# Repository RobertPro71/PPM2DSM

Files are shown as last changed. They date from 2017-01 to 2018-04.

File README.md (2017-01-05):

# PPM2DSM
Control with any transmitter a model with DSM receiver. All information about build, programming and use are here:
www.demoboard.de

## Folder Description

###Layout

The first modul. To build as a single modul that is temporarily connected to the transmitter.

### Layout_fix

A mod of the original converter. To use as fix connection to transmitter.

### Source

Sourcecode written in Arduino with all build tools.

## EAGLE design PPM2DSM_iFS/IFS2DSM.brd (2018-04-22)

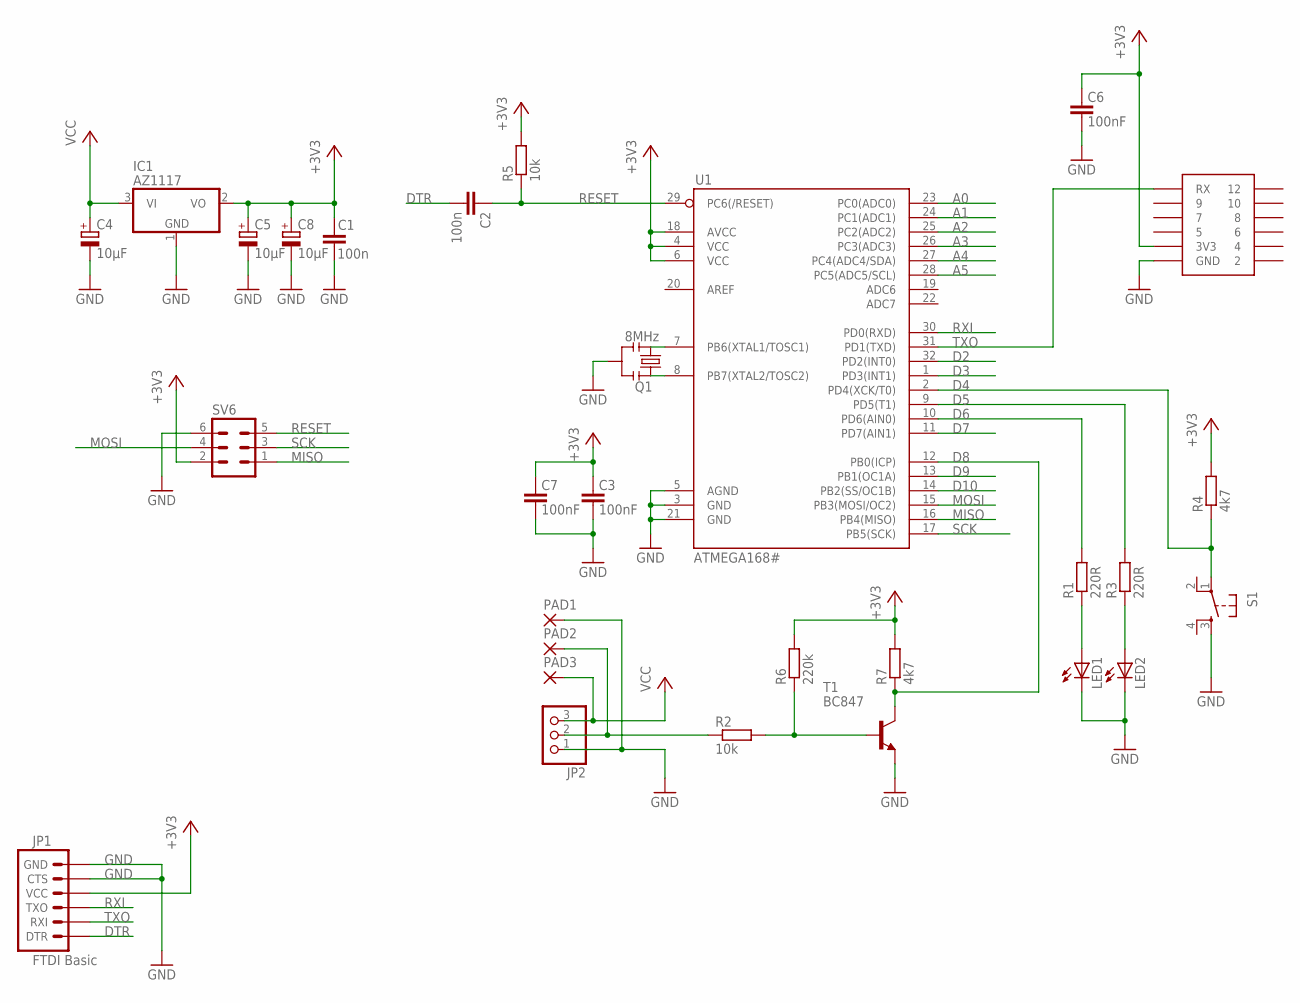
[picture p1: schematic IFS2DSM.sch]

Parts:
C1, C2: 100n; C0805
C3, C6, C7: 100nF; C0805
C4, C5, C8: 10µF; CT6032
IC1: AZ1117; SOT223
IC3: X1TX0
JP1: FTDI Basic; 1X06
JP2: PINHD-1X3_2.00; 1X03M
LED1, LED2: LEDSML0805; SML0805
PAD1, PAD2, PAD3: SMD2; SMD1,27-2,54
Q1: 8MHz; RESONATOR-SMD
R1, R3: 220R; R0805
R2, R5: 10k; R0805
R4, R7: 4k7; R0805
R6: 220k; R0805
S1: 10-XXTASTERSMD; SMD
SV6: MA03-2
T1: BC847; SOT23
U1: ATMEGA168#; TQFP32-08

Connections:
2: IC3.2
4: IC3.4
+3V3: C1.2, C3.2, C5.+, C6.2, C7.2, C8.+, IC1.2 (VO), IC3.3 (3V3), JP1.4 (VCC), R4.2, R5.2, R6.2, R7.2, SV6.2, U1.4 (VCC), U1.6 (VCC), U1.18 (AVCC)
A0: U1.23 (PC0(ADC0))
A1: U1.24 (PC1(ADC1))
A2: U1.25 (PC2(ADC2))
A3: U1.26 (PC3(ADC3))
A4: U1.27 (PC4(ADC4/SDA))
A5: U1.28 (PC5(ADC5/SCL))
D2: U1.32 (PD2(INT0))
D3: U1.1 (PD3(INT1))
D4: R4.1, S1.1, U1.2 (PD4(XCK/T0))
D5: R3.2, U1.9 (PD5(T1))
D6: R1.2, U1.10 (PD6(AIN0))
D7: U1.11 (PD7(AIN1))
D8: R7.1, T1.3 (C), U1.12 (PB0(ICP))
D9: U1.13 (PB1(OC1A))
D10: U1.14 (PB2(SS/OC1B))
DTR: C2.2, JP1.1 (DTR)
GND: C1.1, C3.1, C4.-, C5.-, C6.1, C7.1, C8.-, IC1.1 (GND), IC3.1 (GND), JP1.5 (CTS), JP1.6 (GND), JP2.1, LED1.C, LED2.C, PAD1.1, Q1.2, S1.3 (S), SV6.6, T1.2 (E), U1.3 (GND), U1.5 (AGND), U1.21 (GND)
MISO: SV6.1, U1.16 (PB4(MISO))
MOSI: SV6.4, U1.15 (PB3(MOSI/OC2))
unnamed: Q1.1, U1.8 (PB7(XTAL2/TOSC2))
unnamed: Q1.3, U1.7 (PB6(XTAL1/TOSC1))
unnamed: LED2.A, R3.1
unnamed: R2.2, R6.1, T1.1 (B)
unnamed: JP2.2, PAD2.1, R2.1
unnamed: LED1.A, R1.1
RESET: C2.1, R5.1, SV6.5, U1.29 (PC6(/RESET))
RXI: JP1.3 (TXO), U1.30 (PD0(RXD))
SCK: SV6.3, U1.17 (PB5(SCK))
TXO: IC3.11 (RX), JP1.2 (RXI), U1.31 (PD1(TXD))
VCC: C4.+, IC1.3 (VI), JP2.3, PAD3.1

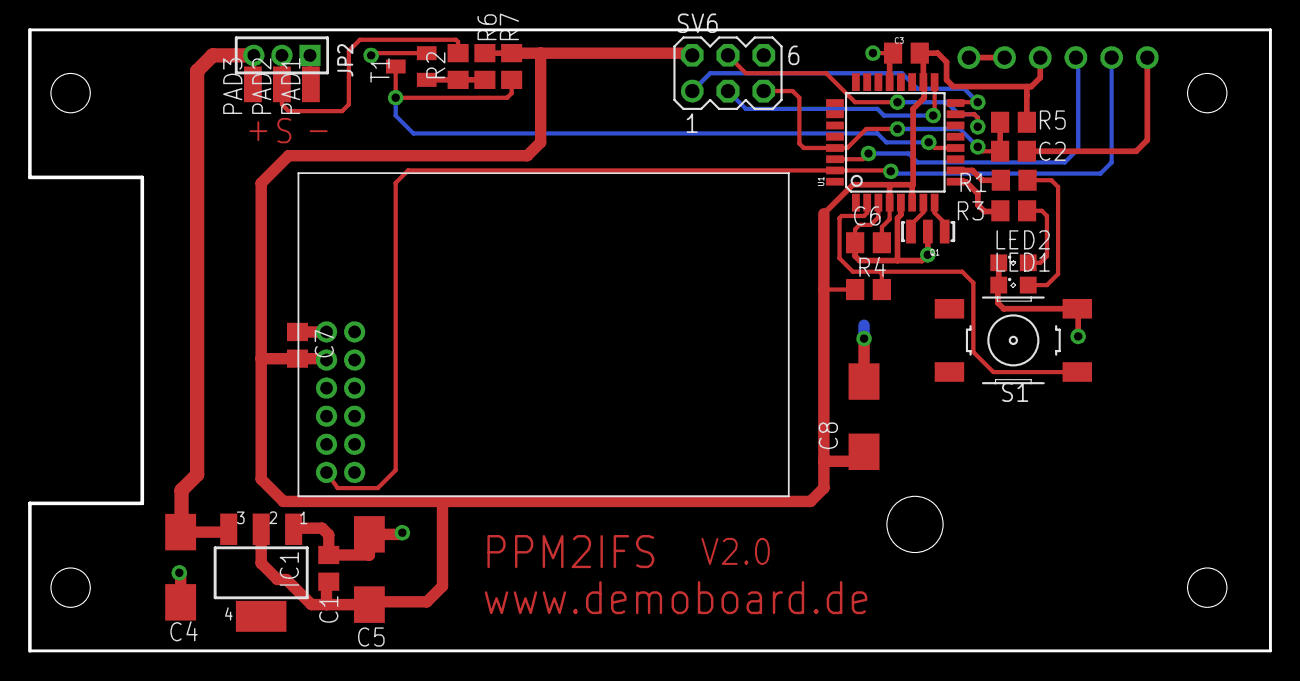
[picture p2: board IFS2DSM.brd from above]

Board: 2 copper layers, 88.3 x 44.2 mm, 29 parts (1 on the bottom side), 20 nets.

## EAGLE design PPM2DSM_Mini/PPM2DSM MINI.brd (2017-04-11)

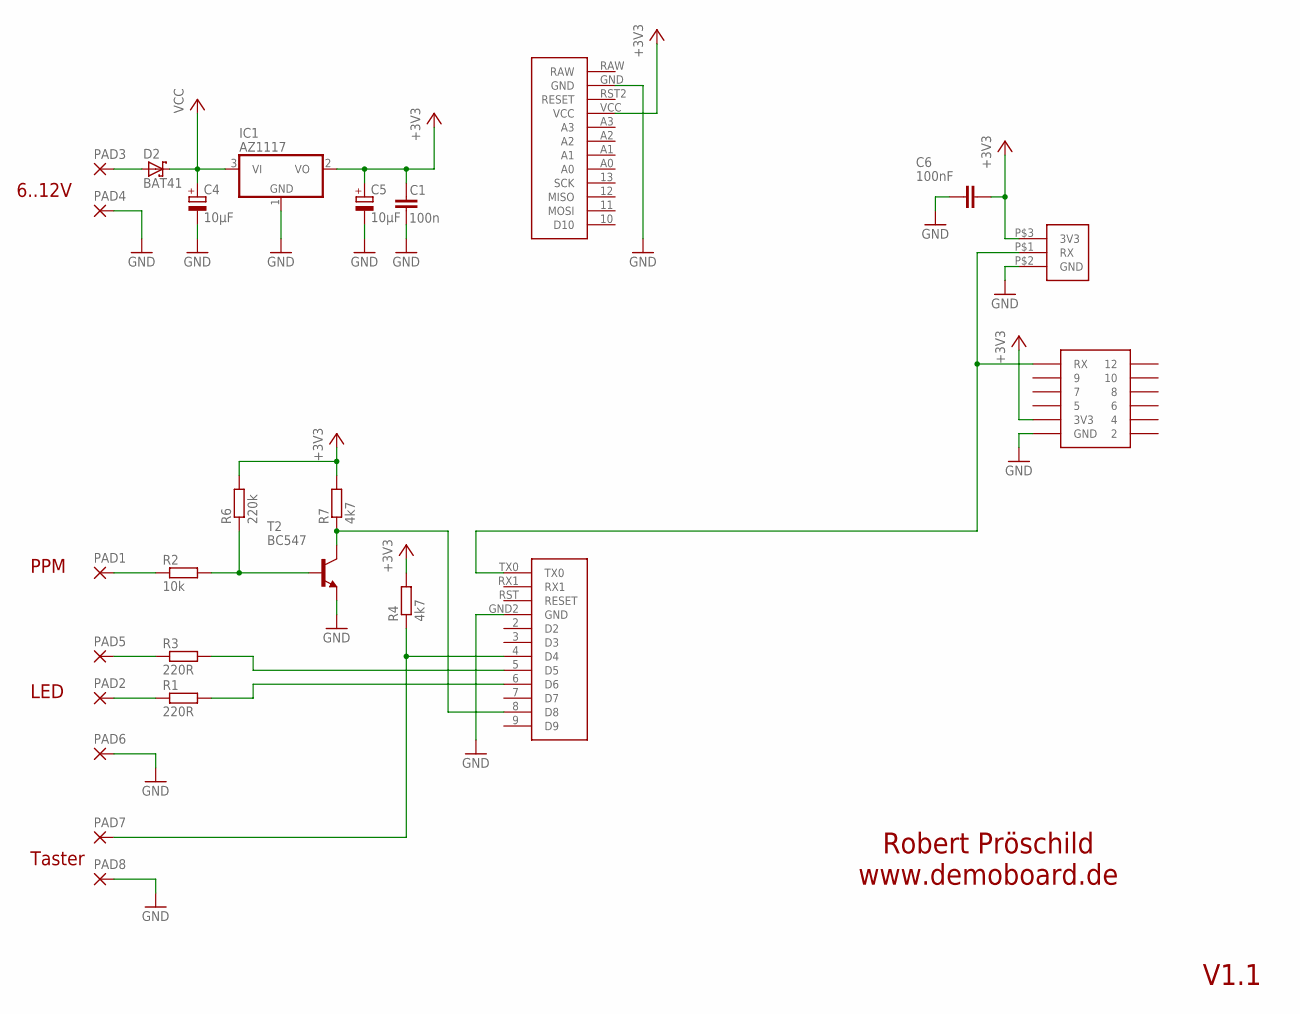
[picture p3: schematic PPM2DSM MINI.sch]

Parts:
C1: 100n; C025-024X044
C4, C5: 10µF; TT2D4
C6: 100nF; C025-024X044
D2: BAT41; DO35-7
IC1: AZ1117; SOT223
IC2: X10EMTX
IC3: MINI_PRO; PRO-MINI
IC4: X1TX0
PAD1, PAD2, PAD3, PAD4, PAD5, PAD6, PAD7, PAD8: SMD5; SMD2,54-5,08
R1, R3: 220R; 0204/5
R2: 10k; 0204/5
R4, R7: 4k7; 0204/5
R6: 220k; 0204/5
T2: BC547; TO92

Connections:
2: IC4.2
4: IC4.4
+3V3: C1.2, C5.+, C6.2, IC1.2 (VO), IC2.P$3 (3V3), IC3.VCC, IC4.3 (3V3), R4.2, R6.2, R7.2
A4: IC3.A4
A5: IC3.A5
D4: IC3.4 (D4), PAD7.1, R4.1
D5: IC3.5 (D5), R3.2
D6: IC3.6 (D6), R1.2
D8: IC3.8 (D8), R7.1, T2.3 (C)
GND: C1.1, C4.-, C5.-, C6.1, IC1.1 (GND), IC2.P$2 (GND), IC3.GND, IC3.GND2 (GND), IC4.1 (GND), PAD4.1, PAD6.1, PAD8.1, T2.1 (E)
unnamed: D2.A, PAD3.1
unnamed: R2.2, R6.1, T2.2 (B)
unnamed: PAD1.1, R2.1
unnamed: PAD2.1, R1.1
unnamed: PAD5.1, R3.1
RAW: IC3.RAW
TXO: IC2.P$1 (RX), IC3.TX0, IC4.11 (RX)
VCC: C4.+, D2.C, IC1.3 (VI)

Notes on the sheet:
6..12V
PPM
LED
Taster
Robert Pröschild www.demoboard.de
V1.1

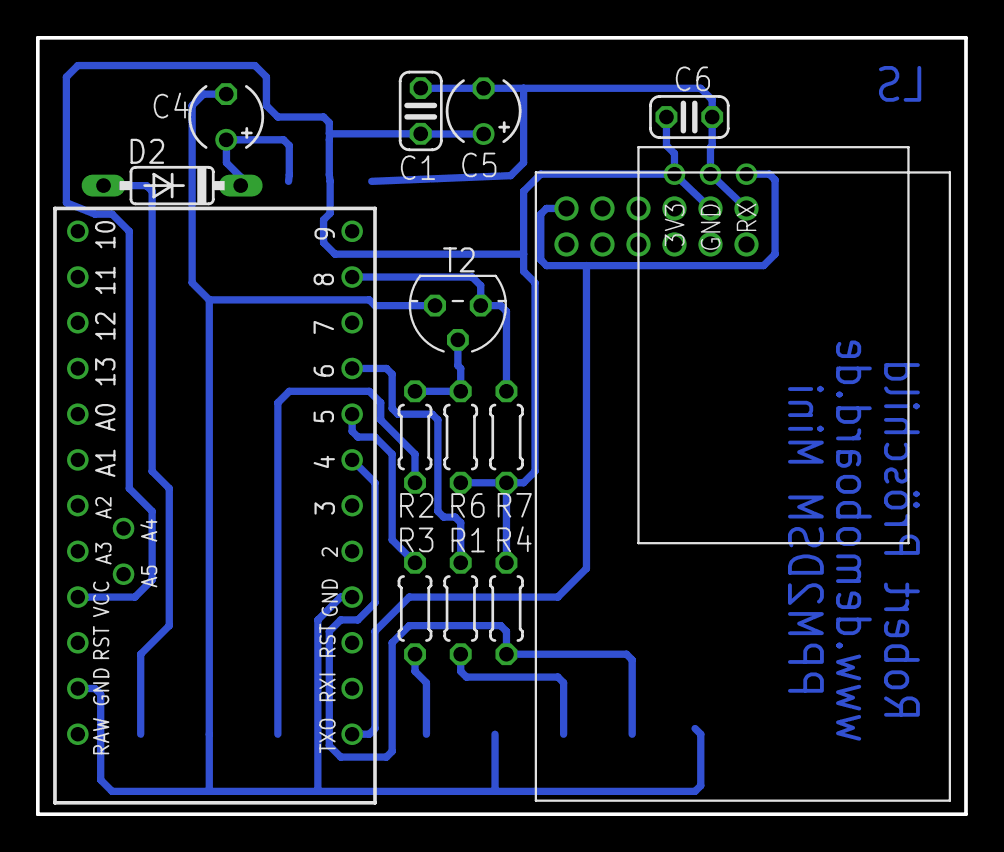
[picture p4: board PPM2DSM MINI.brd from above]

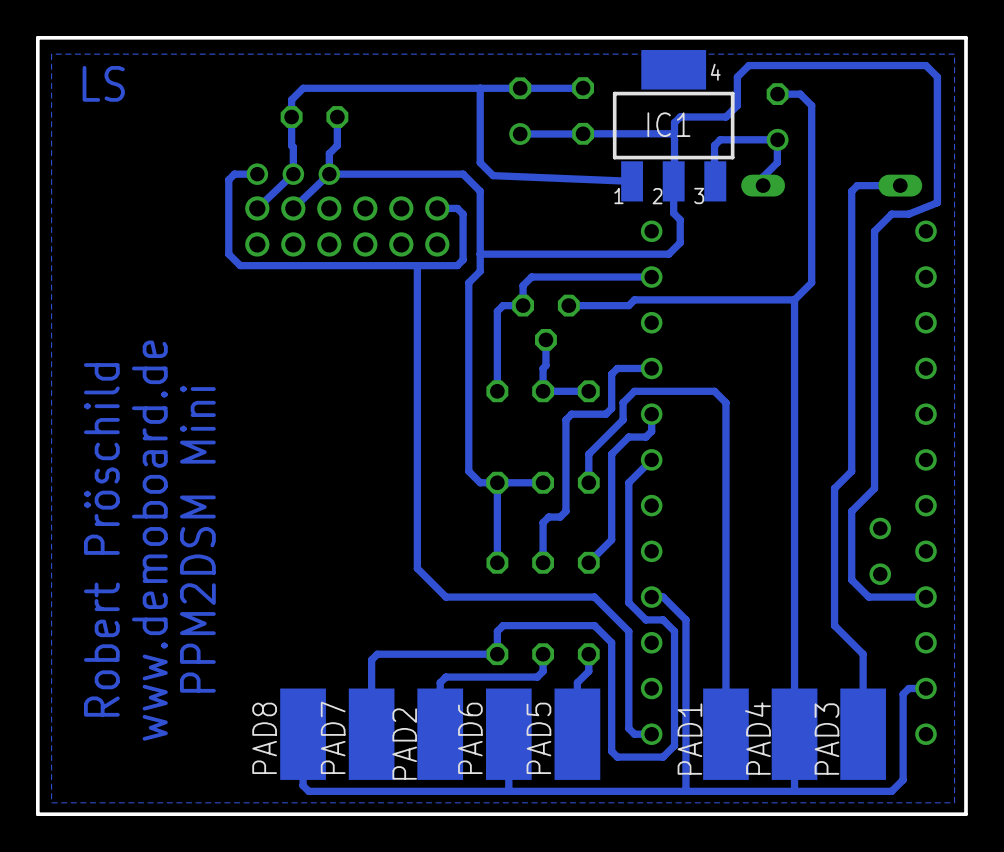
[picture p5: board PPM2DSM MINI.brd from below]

Board: 2 copper layers, 51.6 x 43.1 mm, 24 parts (9 on the bottom side), 13 nets.

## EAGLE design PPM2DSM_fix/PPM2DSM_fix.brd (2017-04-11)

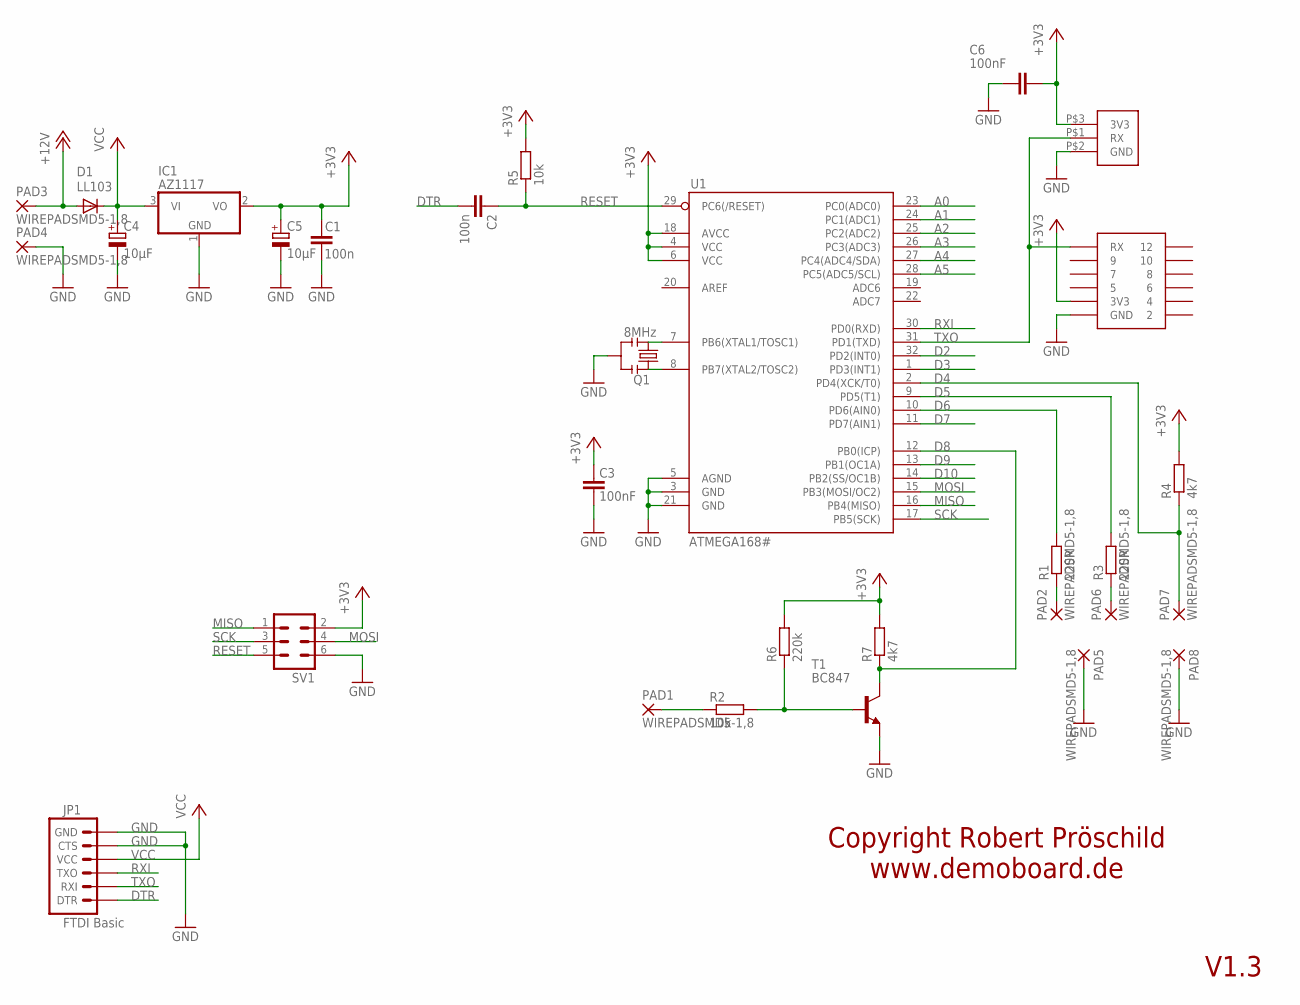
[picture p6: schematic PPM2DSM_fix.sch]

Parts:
C1, C2: 100n; C0805
C3, C6: 100nF; C0805
C4, C5: 10µF; CT6032
D1: LL103; MINIMELF
IC1: AZ1117; SOT223
IC2: X10EMTX
IC3: X1TX0
JP1: FTDI Basic; 1X06
PAD1, PAD2, PAD3, PAD4, PAD5, PAD6, PAD7, PAD8: WIREPADSMD5-1,8; 5-1,8
Q1: 8MHz; RESONATOR-SMD
R1, R3: 220R; R0805
R2, R5: 10k; R0805
R4, R7: 4k7; R0805
R6: 220k; R0805
SV1: MA03-2
T1: BC847; SOT23
U1: ATMEGA168#; TQFP32-08

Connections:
2: IC3.2
4: IC3.4
+3V3: C1.2, C3.2, C5.+, C6.2, IC1.2 (VO), IC2.P$3 (3V3), IC3.3 (3V3), R4.2, R5.2, R6.2, R7.2, SV1.2, U1.4 (VCC), U1.6 (VCC), U1.18 (AVCC)
+12V: D1.A, PAD3.1
A0: U1.23 (PC0(ADC0))
A1: U1.24 (PC1(ADC1))
A2: U1.25 (PC2(ADC2))
A3: U1.26 (PC3(ADC3))
A4: U1.27 (PC4(ADC4/SDA))
A5: U1.28 (PC5(ADC5/SCL))
D2: U1.32 (PD2(INT0))
D3: U1.1 (PD3(INT1))
D4: PAD7.1, R4.1, U1.2 (PD4(XCK/T0))
D5: R3.2, U1.9 (PD5(T1))
D6: R1.2, U1.10 (PD6(AIN0))
D7: U1.11 (PD7(AIN1))
D8: R7.1, T1.3 (C), U1.12 (PB0(ICP))
D9: U1.13 (PB1(OC1A))
D10: U1.14 (PB2(SS/OC1B))
DTR: C2.2, JP1.1 (DTR)
GND: C1.1, C3.1, C4.-, C5.-, C6.1, IC1.1 (GND), IC2.P$2 (GND), IC3.1 (GND), JP1.5 (CTS), JP1.6 (GND), PAD4.1, PAD5.1, PAD8.1, Q1.2, SV1.6, T1.2 (E), U1.3 (GND), U1.5 (AGND), U1.21 (GND)
MISO: SV1.1, U1.16 (PB4(MISO))
MOSI: SV1.4, U1.15 (PB3(MOSI/OC2))
unnamed: Q1.1, U1.8 (PB7(XTAL2/TOSC2))
unnamed: Q1.3, U1.7 (PB6(XTAL1/TOSC1))
unnamed: R2.2, R6.1, T1.1 (B)
unnamed: PAD1.1, R2.1
unnamed: PAD2.1, R1.1
unnamed: PAD6.1, R3.1
RESET: C2.1, R5.1, SV1.5, U1.29 (PC6(/RESET))
RXI: JP1.3 (TXO), U1.30 (PD0(RXD))
SCK: SV1.3, U1.17 (PB5(SCK))
TXO: IC2.P$1 (RX), IC3.11 (RX), JP1.2 (RXI), U1.31 (PD1(TXD))
VCC: C4.+, D1.C, IC1.3 (VI), JP1.4 (VCC)

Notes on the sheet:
Copyright Robert Pröschild www.demoboard.de
V1.3

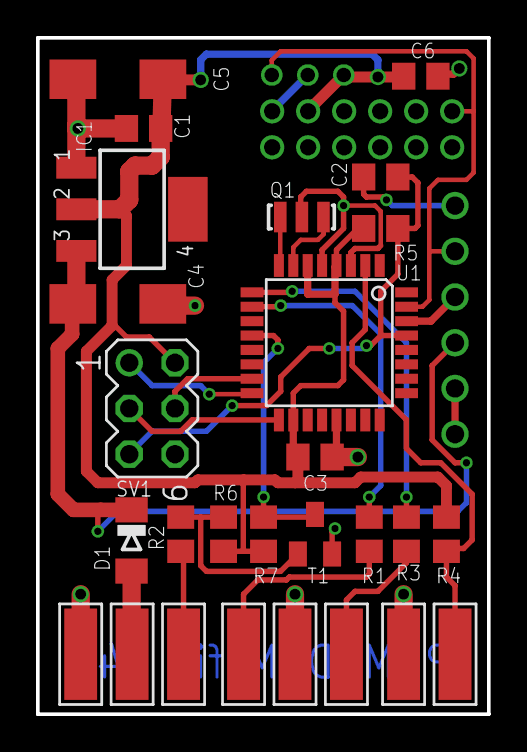
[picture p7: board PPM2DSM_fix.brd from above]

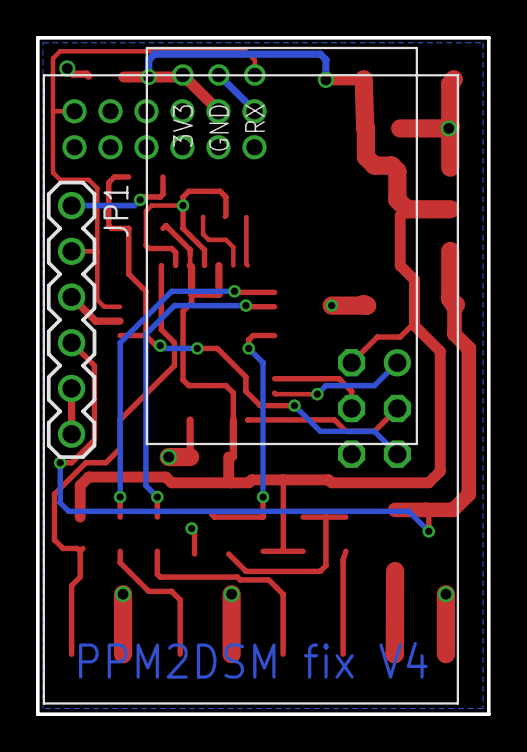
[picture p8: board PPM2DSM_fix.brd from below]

Board: 2 copper layers, 25.1 x 37.6 mm, 30 parts (3 on the bottom side), 21 nets.

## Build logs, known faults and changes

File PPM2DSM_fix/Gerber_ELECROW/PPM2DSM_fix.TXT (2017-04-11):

%
M48
M72
T01C0.0157
T02C0.0236
T03C0.0315
T04C0.0354
T05C0.0400
%
T01
X4713Y6400
X8338Y7150
X9900Y6463
X10650Y7150
X11463Y7150
X12775Y7900
X10588Y10463
X9775Y10400
X8650Y10400
X8713Y11338
X8963Y11650
X6838Y11338
X7150Y9400
X7650Y9150
X10088Y13525
X11025Y13650
T02
X4338Y5025
X9025Y5025
X11400Y5025
X10400Y8025
X4275Y15213
X6963Y16275
X10838Y16338
X12619Y16525
T03
X10091Y16381
X9304Y16381
X8517Y16381
T04
X8525Y15588
X9312Y15588
X10100Y15588
X10887Y15588
X11675Y15588
X12462Y15588
X12462Y14800
X11675Y14800
X10887Y14800
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

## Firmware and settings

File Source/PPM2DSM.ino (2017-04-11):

//Beschreibung der Signale
//Werte eine orginal DX4
//
// Kanal     1         2                    3                   4
// Maximal 0x0353    0x0753 => 0x0353    0x0B53 => 0x0353    0x0F53 => 0x0353     =>   851  dec 
// Mitte   0x01BB    0x05F4 => 0x01FA    0x09FA => 0x01FA    0x0DFA => 0x01FA     =>   506  dec
// Minimal 0x00AA    0x04AA => 0x00AA    0x08AA => 0x00AA    0x0CAA => 0x00AA     =>   170  dec  
//
//  Tool zur Berechnung http://www.arndt-bruenner.de/mathe/9/geradedurchzweipunkte.htm
//
//Multiplex Cockpit MM
//====================
//
//Gemessener Impuls:
//
//         AVR gemessen       Scope gemessen   Logic gemessen
//Maximal  0x76E  = 1,902  =  1,92ms         =  1,90ms
//Mitte    0x5DD  = 1,504  =  ms             =  1,50ms
//Minimal  0x44D  = 1,101  =  1,16ms         =  1,12ms
//
//Errechnet 
//m = 0,85018
//b = -766
//
//Graupner MC16/20
//================
//
//Maximal  0x754  = 1,876  =  1,90ms         =  ms
//Mitte    0x5D0  = 1,488  =  1,52ms         =  ms
//Minimal  0x444  = 1,092  =  1,04ms         =  ms
//
//Errechnet 
//m = 0,89951
//b = -832

//Laut Internet Pulslänge 1,0 - 2,0ms wobei 1,5ms Mittelstellung ist.

//Securety Code
//String         Copyright Robert Proeschild
//String as HEX  0x43 6F 70 79 72 69 67 68 74 20 52 6F 62 65 72 74 20 50 72 6F 65 73 63 68 69 6C 64
//Diff as DEZ      43       
#include "Arduino.h"
#include <avr/interrupt.h>
#include <EEPROM.h>

#define VERSION 6

#define _DEBUG

//Module
#define FULLRANGE
#define _SHORTRANGE

//Transmitter
#define _GRAUPNER_IFS_MC
#define _GRAUPNER_HOTT
#define FUTABA
#define _MULTIPLEX
//Hardware
#define _SINGLE_LED
#define _DEBUG_PIN

#define _WRITE_EEPROM

typedef enum {
    NULL_ST = -1, NOT_SYNCHED, ACQUIRING, READY, FAILSAFE
} State_t;

typedef enum {
  LED_PPM_OK,
  LED_PPM_FAULT,
  LED_PRE_BIND,
  LED_BINDING,
  LED_RANGE_CHECK,
  LED_OFF
} LedMode_t;

typedef enum {
  NO_ERROR,              //0
  EEPROM_DIFF_ERROR,     //1 usw
  EEPROM_SUMM_ERROR,
  NO_PPM_ERROR,
  LAST_ERROR
} Error_t;

#define TICKS_PER_uS      1                 // number of timer ticks per 1 microsecond with prescaler = 8 and CPU 8MHz
#define MAX_CHANNELS      8                 // maximum number of channels we can store, don't increase this above 8
#define MIN_IN_PULSE  ( 750 * TICKS_PER_uS) // valid pulse must be at least   750us
#define MAX_IN_PULSE  (2250 * TICKS_PER_uS) // valid pulse must be less than 2250us
#define SYNC_GAP_LEN  (5000 * TICKS_PER_uS) // we assume a space at least 5000us is sync
#define VALID_FRAMES     10                 // must have this many consecutive valid frames to transition to the ready state.

#define DSM2_CHANNELS      6                // Max number of DSM2 Channels transmitted
#define BINDING_PIN        4                // Pin used to bind
#define BINDING_LED        5                // Pin used for Binding in process LED
#define PPM_OK_LED         6                // Pin used for PPM Ok signal LED
#define SIGNLE_LED         BINDING_LED      //
#define SLOW_FLASH_LED   100                // LED flash interval in ms
#define FAST_FLASH_LED    25                // LED flash interval in ms

#define ISR_DEBUG_PIN     11                // only to Debug the ISR


#define DSM_HEADER_DSMX         0x08
#define DSM_HEADER_EU           0x10
#define DSM_HEADER_BINDING      0x80
#define DSM_HEADER_RANGECHECK   0x20

#define BUTTON_PRESS            LOW
#define BUTTON_RELEASE          HIGH
#define BUTTON_UNDEFINED        3 

#define BUTTON_FILTER_RANGE     11

#define SECURITY_STRING         "Copyright Robert Proeschild look at www.demoboard.de"
#define SECURITY_SUMM           5013
static byte SECURITY_DIFF[] =  {0x43, 0x2C, 0x1F, 0x09, 0x0B, 0x1B, 0x0E, 0x0F, 0x1C, 0x54, 0x72, 0x3D, 0x0D, 0x07, 0x17,
                                0x06, 0x54, 0x70, 0x22, 0x1D, 0x0A, 0x16, 0x10, 0x0B, 0x01, 0x05, 0x08, 0x44, 0x4C, 0x03,
                                0x00, 0x04, 0x4B, 0x41, 0x15, 0x54, 0x57, 0x00, 0x00, 0x59, 0x4A, 0x01, 0x08, 0x02, 0x0D,
                                0x0D, 0x0E, 0x13, 0x16, 0x4A, 0x4A, 0x01, 0x65 };

//GRAUPNER_IFS_MC
#ifdef GRAUPNER_IFS_MC
  #define MODE           1
  #define OFFSET         873
  #define SCALE          0.95506
  static byte ChanIndex[] = {1,2,3,4,5,6};    //PPM to DSM2 Channel Mapping Table
  #define TCCR1B_VALUE   (1<<ICES1) | (1<<CS11)
#endif

//FUTABA
#ifdef FUTABA
  #define MODE           2
  #define OFFSET         1745
  #define SCALE         -0.81459
  static byte ChanIndex[] = {3,1,2,4,5,6};// PPM to DSM2 Channel Mapping Table
  #define TCCR1B_VALUE   (1<<CS11)
#endif

//MULTIPLEX
#ifdef MULTIPLEX
  #define MODE           3
  #define OFFSET         759
  #define SCALE          0.84367
  static byte ChanIndex[] = {4,1,2,3,5,6};    //PPM to DSM2 Channel Mapping Table                                              //Getestet mit Mode 2 Cockpit MM
  #define TCCR1B_VALUE   (1<<ICES1) | (1<<CS11)
#endif


static int Pulses[  MAX_CHANNELS + 1];      // array holding channel pulses width value in microseconds
static int Failsafe[MAX_CHANNELS + 1];      // array holding channel fail safe values
static byte ChannelNum;                     // number of channels detected so far in the frame (first channel is 1)
static byte ChannelCnt;                     // the total number of channels detected in a complete frame
static State_t State;                       // this will be one of the following states: Null, Not_Synched, Acquiring, Ready, Failsafe
static byte stateCount;                     // counts the number of times this state has been repeated

static byte DSM2_Header[2];
static byte DSM2_Channel[DSM2_CHANNELS*2] = {0x00,0xAA,0x05,0xFF,0x09,0xFF,0x0D,0xFF,0x13,0x54,0x14,0xAA};
static byte DSM2_SentFrame = 0;
  
static byte count;
static int pulse;

static unsigned long SlowTimerLED;
static unsigned long FastTimerLED;
static unsigned long TimerDsmSend;
static unsigned int ButtonFiler[BUTTON_FILTER_RANGE];
static unsigned int FilterIdx;
static unsigned int BadCount  = 0;
static unsigned int GoodCount = 0;


/* ---------- ---------- ---------- Sync ---------- ---------- ---------- */
void processSync() {                 // sync pulse was detected so reset the channel to first and update the system state
  Pulses[0] = ICR1 / TICKS_PER_uS;          // save the sync pulse duration for debugging
  if(State == READY)
  {                      
    if( ChannelNum != ChannelCnt)           // if the number of channels is unstable, go into failsafe
      State = FAILSAFE;                     
  }                                         
  else
  {                                    
    if(State == NOT_SYNCHED)
    {              
      State = ACQUIRING;                    // this is the first sync pulse, we need one more to fill the channel data array
      stateCount = 0;                       
    }
    else
    {                                
      if( State == ACQUIRING)
      {             
        if(++stateCount > VALID_FRAMES)
        {
          State = READY;                    // this is the second sync and all channel data is ok so flag that channel data is valid
          ChannelCnt = ChannelNum;          // save the number of channels detected
        }                                   
      }
      else if( State == FAILSAFE)
      {            
          if(ChannelNum == ChannelCnt)      // did we get good pulses on all channels?
            State = READY;                  
        }                                   
    }                                       
  }                                         
  ChannelNum = 0;                           // reset the channel counter
}

/* ---------- ---------- ---------- Interrupt ---------- ---------- ---------- */
ISR(TIMER1_OVF_vect) {

#ifdef DEBUG_PIN
  digitalWrite(ISR_DEBUG_PIN,  HIGH);   
  digitalWrite(ISR_DEBUG_PIN,  LOW);   
#endif

  if(State == READY) {
    State = FAILSAFE;                       // use fail safe values if signal lost
    ChannelNum = 0;                         // reset the channel count
  }                                         
}                                           
                                            
ISR(TIMER1_CAPT_vect) {                     // we want to measure the time to the end of the pulse
	
#ifdef DEBUG_PIN
  digitalWrite(ISR_DEBUG_PIN, HIGH);      
  digitalWrite(ISR_DEBUG_PIN, LOW);     
#endif

  TCNT1 = 0;                                // reset the counter
  if(ICR1 >= SYNC_GAP_LEN)                  // is the space between pulses big enough to be the SYNC
    processSync();                          
  else                                      
    if(ChannelNum < MAX_CHANNELS) {         // check if its a valid channel pulse and save it
      if((ICR1 >= MIN_IN_PULSE) && (ICR1 <= MAX_IN_PULSE)){  // check for valid channel data
        Pulses[++ChannelNum] = ICR1 / TICKS_PER_uS;         // store pulse length as microseconds
      }
      else
      {
        if(State == READY)
        {
          State = FAILSAFE;                 // use fail safe values if input data invalid
          ChannelNum = 0;                   // reset the channel count
          BadCount++;
        }
      }
    }

    if( ChannelNum == ChannelCnt) 
    {
      DSM2_SentFrame = 0;
      GoodCount++;
    }
}

/* ---------- ---------- ---------- Class ---------- ---------- ---------- */
class PPM_Decode {

public:
  PPM_Decode() {                            // Constructor
    // empty                                
  }                                         
                                            
  void begin() {                            
    pinMode(8, INPUT);                      // Timer1 interrupt handler uses pin 8 as input, do not change it
    ChannelNum = 0;                         
    State   = NOT_SYNCHED;                  
    TCCR1A  = 0x00;                         // COM1A1=0, COM1A0=0 => Disconnect Pin OC1 from Timer/Counter 1
                                            //  PWM11=0,  PWM10=0 => PWM Operation disabled
    TCCR1B = TCCR1B_VALUE;        // capture using rising edge,  prescaler = 8
    TIMSK1 = _BV(ICIE1)|_BV (TOIE1);        // enable input capture and overflow interrupts for timer 1
    for(byte ch = 1; ch <= MAX_CHANNELS; ch++) {
      Failsafe[ch] = Pulses[ch] = 1500;     // set midpoint as default values for pulses and failsafe
    }
    Failsafe[3] = Pulses[3] = 1100;       // set channel 3 failsafe pulse width to min throttle
  }

  State_t getState() {
    return State;
  }

  byte getChannelCnt() {
    return ChannelCnt;
  }

  void  setFailsafe(byte ch, int value) {   // pulse width to use if invalid data, value of 0 uses last valid data
    if((ch > 0) && (ch <= MAX_CHANNELS))
      Failsafe[ch] = value;
  }

  void  setFailsafe() {                     // setFailsafe with no arguments sets failsafe for all channels to their current values
    if(State == READY)                      // useful to capture current tx settings as failsafe values
      for(byte ch = 1; ch <= MAX_CHANNELS; ch++)
        Failsafe[ch] = Pulses[ch];
  }

  int getChannelData(uint8_t channel) {     // this is the access function for channel data
    int result = 0;                         // default value
    if(channel <= MAX_CHANNELS)  {
      if((State == FAILSAFE) && (Failsafe[channel] > 0 ))
        result = Failsafe[channel];         // return the channels failsafe value if set and State is Failsafe
      else
        if((State == READY) || (State == FAILSAFE)) {
          cli();                            // disable interrupts
          result = Pulses[channel];         // return the last valid pulse width for this channel
          sei();                            // enable interrupts
        }
    }
    return result;
  }
};

PPM_Decode Receiver = PPM_Decode();

int CheckEeprom()
{
  byte         OldEeprom   = 0;
  byte         ValueEeprom = 0;
  unsigned int SumEeprom   = 0;
  byte         DiffEeprom  = 0;

  for (int adr = 0; adr < sizeof(SECURITY_STRING); adr++)
  {
    ValueEeprom = EEPROM.read(adr);
    SumEeprom = SumEeprom + ValueEeprom;

    //Diff
    DiffEeprom = OldEeprom ^ ValueEeprom;
    OldEeprom = ValueEeprom;

    if(DiffEeprom != SECURITY_DIFF[adr]) return EEPROM_DIFF_ERROR;
  }

  if (SumEeprom != SECURITY_SUMM) return EEPROM_SUMM_ERROR;
  return NO_ERROR;
}


unsigned long StartTimerMs(unsigned long ms)
{
  return (millis() + ms);
}

bool TimePassed(unsigned long Timer)
{
  if (Timer <= millis())
    return true;
  else
    return false;
}

void ErrorLED(byte Error){
  while(true){
    for (int count = Error; count; count--){
      digitalWrite(BINDING_LED, HIGH);
      digitalWrite(PPM_OK_LED, HIGH);
      delay(200);
      digitalWrite(BINDING_LED, LOW);
      digitalWrite(PPM_OK_LED, LOW);
      delay(500);
    }
    delay(4000);
  }
}

void SetLED(byte led_mode) {
  static bool slow_flasching;
  static bool fast_flasching;

  if(TimePassed(SlowTimerLED))
  {
    slow_flasching = !slow_flasching;
    SlowTimerLED  = StartTimerMs( SLOW_FLASH_LED );
  }               

#ifdef SINGLE_LED  
  if(TimePassed(FastTimerLED))
  {
    fast_flasching = !fast_flasching;
    FastTimerLED  = StartTimerMs( FAST_FLASH_LED );
  }               
#endif
  
  switch( led_mode )
  {

#ifdef SINGLE_LED
    case LED_PRE_BIND :
      digitalWrite(SIGNLE_LED, fast_flasching);
    break;    
    
    case LED_BINDING :
      digitalWrite(SIGNLE_LED, slow_flasching);
    break;
  
    case LED_PPM_OK :
      digitalWrite(SIGNLE_LED, LOW );     
    break;

    case LED_PPM_FAULT :
      digitalWrite(SIGNLE_LED, HIGH);     
    break;

    case LED_OFF :
      digitalWrite(SIGNLE_LED, LOW);     
    break;

#else
    case LED_PRE_BIND :
      digitalWrite(BINDING_LED, slow_flasching);
      digitalWrite(PPM_OK_LED,  !slow_flasching);      
    break;    
    
    case LED_BINDING :
      digitalWrite(BINDING_LED, slow_flasching);
      digitalWrite(PPM_OK_LED,  LOW);      
    break;
  
    case LED_PPM_OK :
      digitalWrite(BINDING_LED, LOW );     
      digitalWrite(PPM_OK_LED,  slow_flasching);
    break;

    case LED_PPM_FAULT :
      digitalWrite(BINDING_LED, HIGH);     
      digitalWrite(PPM_OK_LED,  LOW);   
    break;
    case LED_OFF :
      digitalWrite(BINDING_LED, LOW);     
      digitalWrite(PPM_OK_LED,  LOW);   
    break;
#endif  
  }
};

void SendNormalFrame( byte Header)
{
  //Set normal header
#ifdef FULLRANGE
  DSM2_Header[0] = Header;
#endif
#ifdef SHORTRANGE
  DSM2_Header[0] = 0x59;
  DSM2_Header[1] = 0x00;
#endif

  if(Receiver.getState() == READY || Receiver.getState() == FAILSAFE) {
    if(ChannelNum == 0 || ChannelNum == ChannelCnt) {   // during sync pulse or in failsafe
      if(DSM2_SentFrame == 0)                  // if DSM2 frame is not sent yet
      {
        for (byte i=0; i<DSM2_CHANNELS; i++) // get receiver data
        {
//          pulse = Receiver.getChannelData(ChanIndex[i]) - 1000; //Offset der min. Stellung
          pulse = int(Receiver.getChannelData(ChanIndex[i]) * SCALE) - OFFSET;
       
          pulse = constrain(pulse, 0, 0x3FF);
          DSM2_Channel[i*2]   = (byte)(i<<2) | highByte(pulse);
          DSM2_Channel[i*2+1] = lowByte(pulse);
        }
        sendDSM2();                         // send frame
        DSM2_SentFrame = 1;                      // frame sent flag
      } else {
        if(Receiver.getState() == FAILSAFE) {
          delay(20);                        // in case of failsafe
          DSM2_SentFrame = 0;                    // reset flag after delay
        }
      }
    } 
  }
}

void SendBindingFrame( byte Header)
{
#ifdef FULLRANGE
  DSM2_Header[0] = Header;
#endif
#ifdef SHORTRANGE
  DSM2_Header[0] = 0x80;
#endif
  DSM2_Header[1] = 0;
  sendDSM2();
}

unsigned int GetFilerBindingButton()
{
  unsigned int Result = BUTTON_UNDEFINED;
  
  ButtonFiler[FilterIdx] = digitalRead(BINDING_PIN);
  if( ++FilterIdx == BUTTON_FILTER_RANGE) FilterIdx = 0;
  
  int FilterSumme = 0;
  for( int i = 0; i < BUTTON_FILTER_RANGE; i++)
  {
    FilterSumme += ButtonFiler[i]; 
  }
  
  if (FilterSumme == 0)                   Result = LOW;
  if (FilterSumme == BUTTON_FILTER_RANGE) Result = HIGH;

  return Result;
}


void setup() {
  byte idx;
  byte mode;
  byte maxpulse;
  delay(100);

  pinMode(BINDING_PIN, INPUT);
  pinMode(BINDING_LED, OUTPUT);
  pinMode(PPM_OK_LED,  OUTPUT);
  pinMode(ISR_DEBUG_PIN,  OUTPUT);
  digitalWrite(BINDING_LED, LOW);
  digitalWrite(PPM_OK_LED, LOW);

  //Tell Version via LED
  mode = MODE;
#ifdef SHORTRANGE
  mode += 10;
#endif  
  maxpulse = max(VERSION, mode);
  for (idx = 0; idx <= maxpulse; idx++)
  {
     if(VERSION > idx) digitalWrite(BINDING_LED, HIGH);
     if(mode    > idx) digitalWrite(PPM_OK_LED, HIGH);
     delay(1); 
     digitalWrite(BINDING_LED, LOW);
     digitalWrite(PPM_OK_LED, LOW);
     delay(1); 
  } 
  delay(10); 


  #ifdef WRITE_EEPROM
    //Schreibt den securety string into EEPROM
    char securety[] = SECURITY_STRING;
    for (idx = 0; idx < sizeof(securety); idx++)
    {
      EEPROM.write(idx, securety[idx]); 
    }
  
    while (true)
    {
      digitalWrite(BINDING_LED, HIGH);
      delay(50);
      digitalWrite(BINDING_LED, LOW);
      delay(50);
    }
  #endif
  
  //Initialisieren der RS232
  #ifdef DEBUG
  Serial.begin(115200);      // print values on the screen
  #else
    #ifdef FULLRANGE
      Serial.begin(125000);    // closest speed for DSM2 module, otherwise it won't work
    #endif
    #ifdef SHORTRANGE
      Serial.begin(138000);    // closest speed for DSM2 module, otherwise it won't work
    #endif  
  #endif

  int CheckEepromResult = CheckEeprom(); 
  if (CheckEepromResult != NO_ERROR)
  {
    ErrorLED(CheckEepromResult);
  }
   
 
  //Init Button Filter
  for (int i = BUTTON_FILTER_RANGE; i; i--)
  {
    ButtonFiler[i -1] = digitalRead(BINDING_PIN);
  }
  FilterIdx = 0;


  //Starte PPM Erkennung
  Receiver.begin();
  //IO festelegen

  delay(100);

  //Warten auf ein stabiles Signal
  count = 50;
  while(Receiver.getState() != READY) // wait 5 sec or until PPM data is stable and ready
  {
    delay(100);
    SetLED(LED_PPM_FAULT);
    count--;
    if (count == 0)
    {
      ErrorLED(NO_PPM_ERROR);
    }
  }

  //Start Timer
  SlowTimerLED = StartTimerMs( 0 );
  TimerDsmSend = StartTimerMs( 0 );

  //Binding oder nicht?
  while(GetFilerBindingButton() == BUTTON_UNDEFINED);
  if(GetFilerBindingButton() == BUTTON_RELEASE) // Kein Binding
  {
    //Erste Frames senden
    #ifdef FULLRANGE
      DSM2_Header[0] = DSM_HEADER_DSMX | DSM_HEADER_EU;
      DSM2_Header[1] = 0x00;
    #endif
    #ifdef SHORTRANGE
      //One Time a sync
      DSM2_Header[0] = 0x58;
      DSM2_Header[1] = 0x00;
    #endif
    sendDSM2();
    delay(20);
  }
  else //Binding
  {              
    //Warten bis der Taster losgelassen wird
    while ((GetFilerBindingButton() == BUTTON_PRESS) || (GetFilerBindingButton() == BUTTON_UNDEFINED)) 
    {
      SetLED(LED_PPM_FAULT);
    }

    //Taster wurde los gelassen und warten auf erneutes dr�cken    
    while ((GetFilerBindingButton() == BUTTON_RELEASE) || (GetFilerBindingButton() == BUTTON_UNDEFINED))
    {
      SetLED(LED_PRE_BIND);
    }

    //Binding aktiv
    while ((GetFilerBindingButton() == BUTTON_PRESS) || (GetFilerBindingButton() == BUTTON_UNDEFINED))
    {
      SendBindingFrame( DSM_HEADER_DSMX | DSM_HEADER_EU | DSM_HEADER_BINDING );
      SetLED(LED_BINDING);
      delay(20);
    }
    
    //Ende Binding
  }
  
}



 ///////////////////////////////////////////////////////////////////////////
void loop() {
	if(GetFilerBindingButton() == BUTTON_PRESS)
	{
		SendNormalFrame( DSM_HEADER_DSMX | DSM_HEADER_EU | DSM_HEADER_RANGECHECK);
		SetLED(LED_PPM_FAULT);
	}
	else
	{
		SendNormalFrame( DSM_HEADER_DSMX | DSM_HEADER_EU);      
		if(Receiver.getState() == READY) SetLED(LED_PPM_OK);
		else                             SetLED(LED_PPM_FAULT);
	}

}

#ifndef DEBUG
void sendDSM2() {
    Serial.write(DSM2_Header, 2);
#ifdef SHORTRANGE
    DSM2_Channel [8] = 0x13;
    DSM2_Channel [9] = 0x54;
    DSM2_Channel[10] = 0x14;
    DSM2_Channel[11] = 0xAA;
#endif    
    Serial.write(DSM2_Channel, DSM2_CHANNELS*2);
}

#else
void sendDSM2() {
//    Serial.print(DSM2_Header[0], HEX);
//    Serial.print("   ");
//    Serial.print(DSM2_Header[1], HEX);
//    Serial.print("   ");
    for(byte i=0; i < DSM2_CHANNELS; i++) { // print channels 1 to 6 in Hex and Dec
      serialPrintHex(DSM2_Channel[i*2]);
      Serial.print(" ");
      serialPrintHex(DSM2_Channel[i*2+1]);
      Serial.print(" (");
      Serial.print((DSM2_Channel[i*2]&0x03)<<8 | DSM2_Channel[i*2+1], DEC);
      Serial.print(")  -");
      Serial.print(Receiver.getChannelData(i + 1), DEC);
      Serial.print("-  ");
    }
    Serial.print("  ");
    Serial.print(Receiver.getChannelData(0), DEC);  // sync pulse length
    
//    Serial.print(" G ");
//    Serial.print(GoodCount, DEC);  // sync pulse length
//    Serial.print(" B ");
//    Serial.print(BadCount, DEC);  // sync pulse length
    
    Serial.println(" ");
    delay(200);
}

void serialPrintHex(byte b) {
    byte b1 = (b >> 4) & 0x0F;
    byte b2 = (b & 0x0F);
    char c1 = (b1 < 10) ? ('0' + b1) : 'A' + b1 - 10;
    char c2 = (b2 < 10) ? ('0' + b2) : 'A' + b2 - 10;
    Serial.print(c1);
    Serial.print(c2);
}
#endif

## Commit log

2017-01-05 First Try
    [PPM2DSM.brd, PPM2DSM.sch, PPM2DSM_fix.brd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]
2017-04-11 Add PPM2DSM PCB
    [PPM2DSM.brd, PPM2DSM.sch]
2017-04-11 Add PPM2DSM_fix PCB
    [PPM2DSM_fix.brd, PPM2DSM_fix.sch]
2017-04-11 Add PPM2DSM MINI PCB
    [PPM2DSM MINI.brd, PPM2DSM MINI.sch]
2017-04-11 Add Gerber files to use with elecrow
    [PPM2DSM MINI.GBL, PPM2DSM MINI.GBO, PPM2DSM MINI.GBS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]
2018-04-22 Add iFS pcb
    [IFS2DSM.brd, IFS2DSM.sch]

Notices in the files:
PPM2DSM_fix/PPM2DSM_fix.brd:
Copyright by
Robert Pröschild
